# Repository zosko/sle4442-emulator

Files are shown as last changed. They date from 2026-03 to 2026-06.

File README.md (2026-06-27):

# SLE4442 Emulator
This is a smartcard emulator for ATMEGA8 microcontroller.

## Schematic
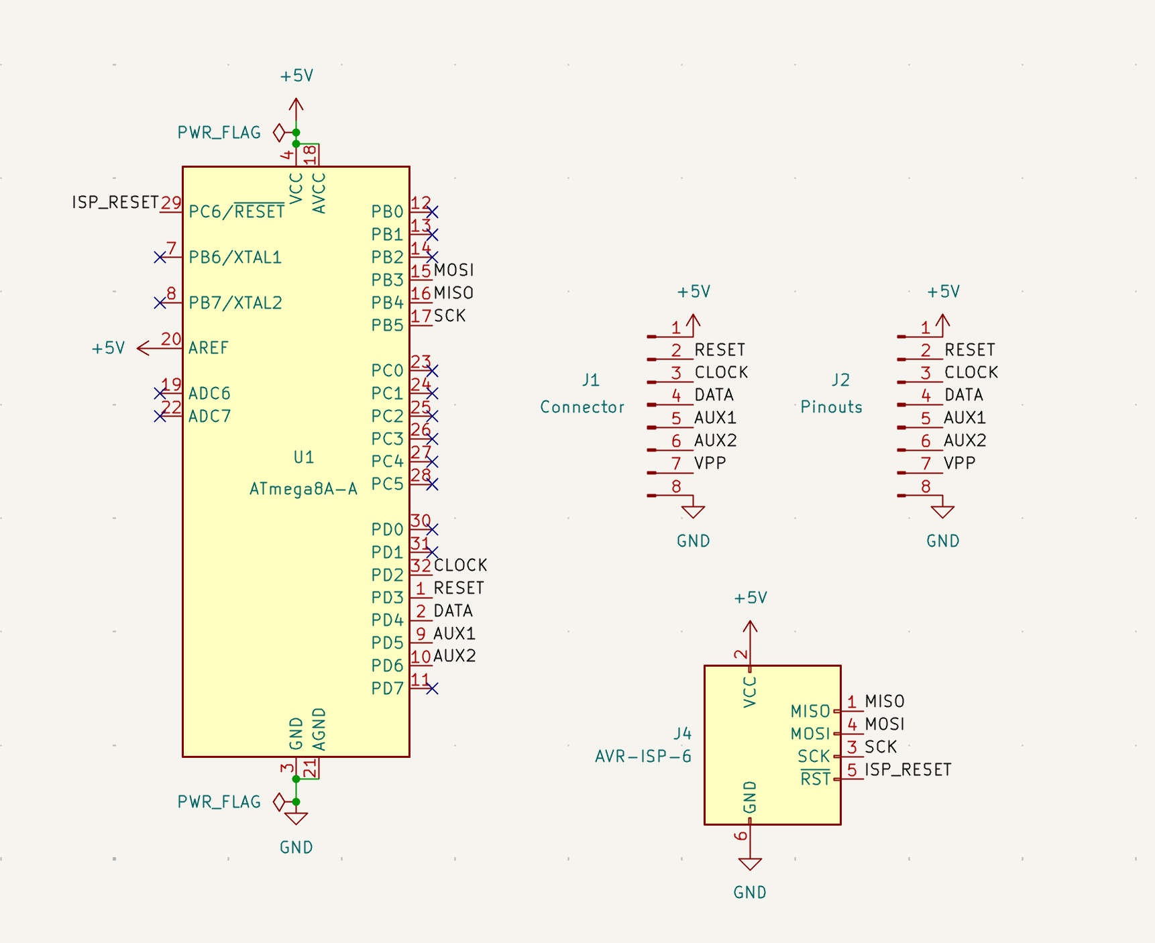
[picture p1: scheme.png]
Schematic


## Schematic
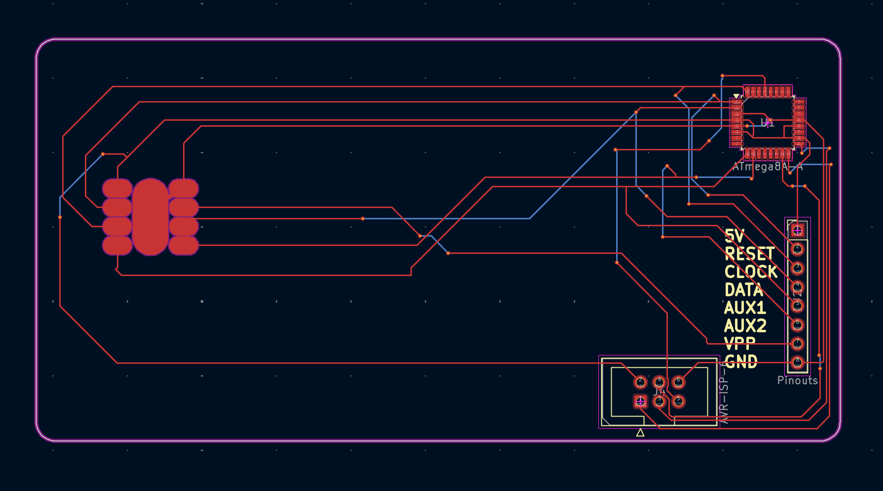
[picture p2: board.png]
Board


## Instructions
- Modify the "memory.h" file with the data of the card that you want to emulate
- If you compile the file with "#define BACKDOOR" uncommented, you will emulate a card that will be unlocked using any PSC code. Also, the PSC code sent by the reader will be updated immediately on the Security memory.  
- **WARNING**  
The maximum input clock frequency will be around 35KHz, not the 50KHz specified in the SLE4442 datasheet. I've tried my best to optimize the code but this is the main limitation of this project, you can try to use an external 16MHz clock for a better performance.

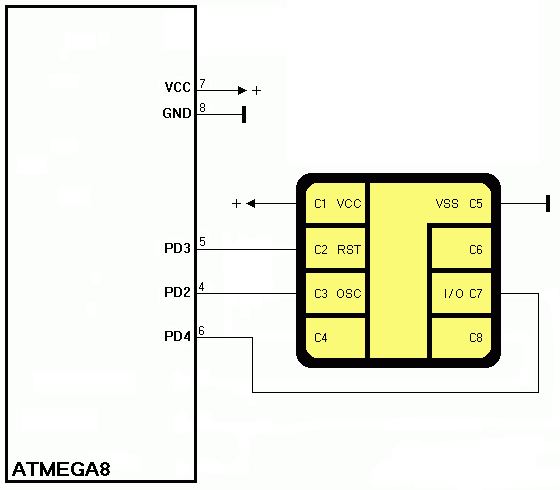
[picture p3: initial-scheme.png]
Old

Real scheme used from https://github.com/sonovice/sle4442.

# Programming instruction
```
brew tap osx-cross/avr
brew install avr-gcc avrdude
```

The following commands are for USBasp programmer. For other programmers, look at the avrdude documentation.  

## Writing fuses
Execute those commands only one time, no need to write fuses every time you burn the flash.
```
make fuses
```

## Burning
Go in `code` folder. Execute this command:

```
make flash
```

## Read EEPROM
Once the PSC is grabbed, you can read the microcontroller EEPROM using this command:
```
make read
```

Open **eeprom.hex** with a text editor, PSC is present here:


## Sponsorship

PCBWay_logo

**This project is proudly sponsored by [PCBWay](https://pcbway.com).**

PCBWay specializes in manufacturing high-quality printed circuit boards (PCBs), making them accessible and affordable for both hobbyists and professionals.

Their range of services includes:

- PCB prototyping
- Assembly services
- Instant order quotations
- Expert verification processes
- A user-friendly, hassle-free ordering system

I'm sincerely grateful to PCBWay for their generous support in making this project possible.

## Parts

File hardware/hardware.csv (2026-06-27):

Reference | Qty | Value | MPN | LCSC Part #
J1 | 1 | Connector
J2 | 1 | Pinouts
J4 | 1 | AVR-ISP-6
U1 | 1 | ATmega8A-A | ATMEGA8A-AU | C16190
Y1 | 1 | 16Mhz | CSTCE16M0V53-R0 | C32180

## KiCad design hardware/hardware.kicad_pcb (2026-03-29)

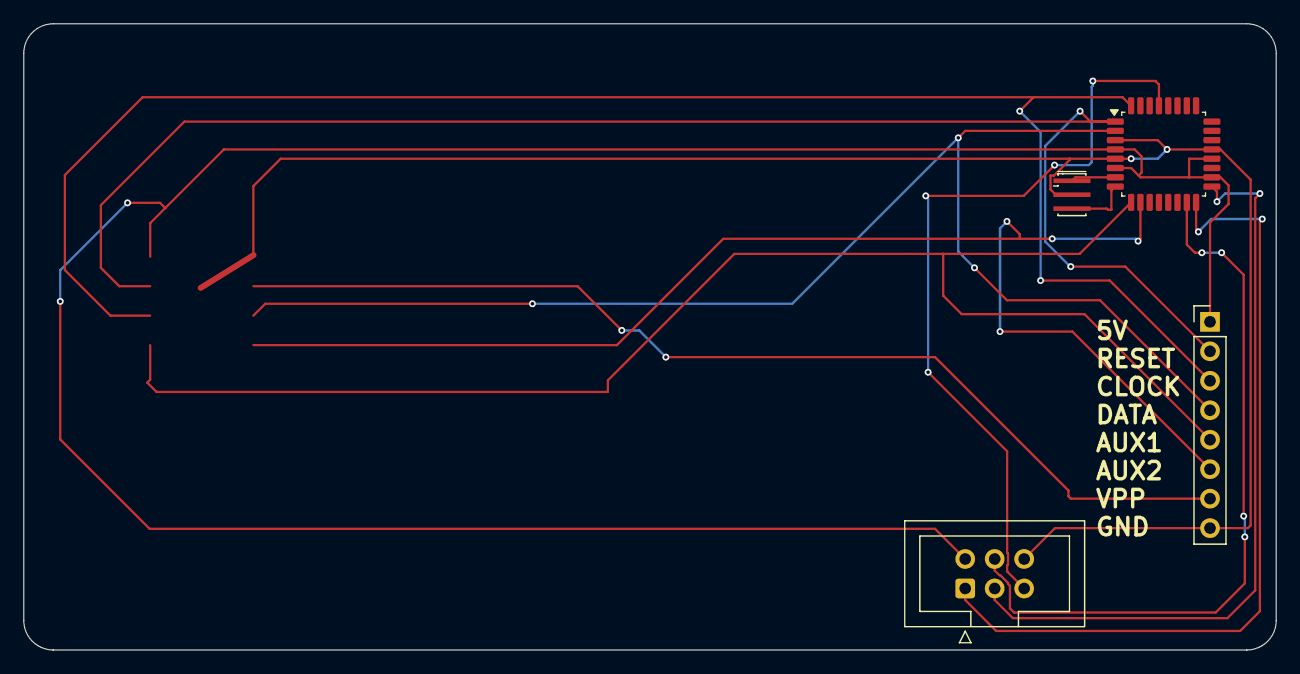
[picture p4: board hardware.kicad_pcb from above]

Board: 2 copper layers, 108.0 x 54.0 mm, 4 parts (0 on the bottom side), 13 nets.

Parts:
J2: Pinouts; PinHeader_1x08_P2.54mm_Vertical
J4: AVR-ISP-6; IDC-Header_2x03_P2.54mm_Vertical
U1: ATmega8A-A; TQFP-32_7x7mm_P0.8mm
Y1: 16Mhz; Resonator_SMD_Murata_CSTxExxV-3Pin_3.0x1.1mm_HandSoldering

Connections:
+5V: J2.1, J4.2 (VCC), U1.4 (VCC), U1.6 (VCC), U1.18 (AVCC), U1.20 (AREF)
/AUX1: J2.5, U1.9 (PD5)
/AUX2: J2.6, U1.10 (PD6)
/CLOCK: J2.3, U1.32 (PD2)
/DATA: J2.4, U1.2 (PD4)
/ISP_RESET: J4.5 (~RST), U1.29 (PC6/~RESET)
/MISO: J4.1 (MISO), U1.16 (PB4)
/MOSI: J4.4 (MOSI), U1.15 (PB3)
/RESET: J2.2, U1.1 (PD3)
/SCK: J4.3 (SCK), U1.17 (PB5)
GND: J2.8, J4.6 (GND), U1.3 (GND), U1.5 (GND), U1.21 (AGND), Y1.2
unnamed: U1.7 (PB6/XTAL1), Y1.1
unnamed: U1.8 (PB7/XTAL2), Y1.3

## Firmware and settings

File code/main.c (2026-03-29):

// cpu: ATMega8
// speed: 8 MHz

//#define DEBUG
#define BACKDOOR

#define F_CPU 8000000UL
#include "sle4442.h"
#include "memory.h"
#include <avr/io.h>
#include <util/delay.h>
#include <stdlib.h>
#include <stdio.h>
#include <stdlib.h>

volatile unsigned char is_start = 0;
volatile unsigned char is_stop = 0;
volatile unsigned char data_out = 0;
volatile unsigned char data_in = 0;
volatile unsigned char is_falling=0;
volatile unsigned char is_rising=0;
volatile unsigned char exec_reset=0;

volatile unsigned char count=0;
volatile unsigned char control=0;
volatile unsigned int  addr=0;
volatile unsigned char data=0;
volatile unsigned char cmd=0;
volatile unsigned char fail=0;
volatile unsigned char byteProt=0;
volatile unsigned char bitProt=0;
volatile unsigned char *memPtr;

void EEPROM_write(unsigned int uiAddress, unsigned char ucData)
{
    /* Wait for completion of previous write */
    while(EECR & (1<<EEWE));
    /* Set up address and data registers */
    EEAR = uiAddress;EEDR = ucData;
    /* Write logical one to EEMWE */
    EECR |= (1<<EEMWE);
    /* Start eeprom write by setting EEWE */
    EECR |= (1<<EEWE);
}

void store_psc()
{
    cli();
    EEPROM_write(0x00,memorySecurity[1]);
    EEPROM_write(0x01,memorySecurity[2]);
    EEPROM_write(0x02,memorySecurity[3]);
    sei();
}

static inline void  falling_clock()
{
    data_out = (memPtr[addr] >> pointerBit) & 0x01;
    
    if (control==0xFF)  //Fake "control" value for put at the output the ATR
    {
        if (addr==4 && pointerBit==1)
        {
            setInput();
            mode = MODE_WAIT_START;
            count = 0;
        }
    }
    else if (control==0x30)
    {
        if (addr==256 && pointerBit==1)
        {
            setInput();
            mode = MODE_WAIT_START;
            count = 0;
        }
    }
    else if (control==0x34)
    {
        if (addr==4 && pointerBit==1)
        {
            setInput();
            mode = MODE_WAIT_START;
            count = 0;
        }
    }
    else if (control==0x31)
    {
        if (addr==4 && pointerBit==1)
        {
            setInput();
            mode = MODE_WAIT_START;
            count = 0;
        }
    }
    else if (fail)
    {
        if (addr==0 && pointerBit==3)
        {
            fail = 0;
            setInput();
            mode = MODE_WAIT_START;
            count = 0;
        }
    }
    else if ((control==0x38 || control==0x3C) && fail==0)
    {
        if (addr==15 && pointerBit==5)  //15*8 + 5 = 125
        {
            setInput();
            mode = MODE_WAIT_START;
            count = 0;
        }
    }
    
    pointerBit++;
    if (pointerBit==8)
    {
        pointerBit = 0;
        addr++;
    }
}

static inline void  rising_clock()
{
    cmd = (cmd << 1) | data_in;
    if (count==7) //control ready
        control = lut[cmd];
    else if (count==15) //address ready
    {
        addr = lut[cmd];
        //Put as output all zero, if i found a read command i change the pointer value
        memPtr = memoryZero;
        if (control==0x30) //Read Main Memory
            memPtr = memoryMain;
        else if (control==0x34) //Read Protection Memory
        {
            addr = 0;
            memPtr = memoryProtected;
        }
        else if (control==0x31) //Read Security Memory
        {
            addr = 0;
            memoryOut[0] = memorySecurity[0];
            if (unlocked == 3)
                memPtr = memorySecurity;
            else
                memPtr = memoryOut;
        }
        byteProt = (addr >> 3) & 0x03;
        bitProt = addr & 0x07;
    }
    else if (count==16) //Use this extra counter value to execute some instructions
    {
        fail = 1;
        if (control==0x38 && unlocked==3) //Update main memory
        {
            if (addr>31)
                fail = 0;
            else
                fail = !((memoryProtected[byteProt] >> bitProt) & 0x01);
        }
        else if (control==0x3C && unlocked==3) //Write protection memory
        {
            if ((memoryProtected[byteProt] >> bitProt) & 0x01)
                fail = 0;
            addr = 0;
        }
        
    }
    else if (count==23) //data ready
    {
        mode = MODE_WAIT_STOP;
        pointerBit = 0;
        data = lut[cmd];
        
        if (control==0x38) //Update main memory
        {
            if (!fail)
                memoryMain[addr] = data;
            addr = 0;
        }
        else if (control==0x3C) //Write protection memory
        {
            if (!fail)
                memoryProtected[byteProt] &= ~(1 << bitProt);
            addr = 0;
        }
        else if (control==0x39) //Update security memory
        {
            if (unlocked == 3)
            {
                memorySecurity[addr] = data;
                memorySecurity[0x00] &= 0x07;
                fail = 0;
            }
            else if (addr == 0x00)
            {
                if (data <= memorySecurity[0x00])
                {
                    memorySecurity[0x00] = data;
                    fail = 0;
                }
                else
                fail = 1;
            }
            addr = 0;
        }
        else if (control==0x33) //Compare verification data
        {
            #ifdef BACKDOOR
                if (addr != 0)
                {
                    unlocked++;
                    memorySecurity[addr] = data;
                    if (unlocked >= 3)
                    {
                        unlocked = 3;
                        memorySecurity[0x00] = 0x07;
                    }       
                }
                addr = 0;
            #else
                if ((memorySecurity[addr] == data) & (memorySecurity[0x00] != 0x00))
                {
                    unlocked++;
                    if (unlocked >= 3)
                    {
                        unlocked = 3;
                        memorySecurity[0x00] = 0x07;
                    }
                }
                else
                    unlocked = 0;
                addr = 0;
            #endif
        }
        
        data_out = (unsigned char)(memPtr[addr]) & 0x01;
        pointerBit++;
    }
    
    count++;  
}

// Clock interrupt
ISR(INT0_vect)
{
    //SET_DBG
    data_in = (READ_IO) >> PIN_IO;  
    if (!(PIN & (1 << PIN_CLK)))
    {
        setIO(data_out);
        
        if (is_start && !data_in)
        {
            pointerBit = 0;
            setMode(MODE_CMD);
            is_start = 0;     
        }
        else if (is_stop && data_in)
        {
            setMode(MODE_OUT);
            setOutput();  
            is_stop=0;  
        }
 
        if (mode==MODE_OUT)
            falling_clock();
    }    
    else
    { 
        if (PIN & (1 << PIN_RST))
        {
            setOutput();
            setMode(MODE_OUT);
        }        
        else if (data_in && mode==MODE_WAIT_START)
            is_start = 1;         
        else if (!data_in && mode==MODE_WAIT_STOP)
            is_stop = 1;
        
        if (mode==MODE_CMD)
            rising_clock();       
    }   
    //RESET_DBG 
}

// Reset interrupt
ISR(INT1_vect)
{
    exec_reset = 1;
}

int main(void) {
    
    memPtr = memoryMain;
    
    unlocked = 0;
    
    // Activate interrupts
    MCUCR |= (1 << ISC00) | (1 << ISC11) | (1 << ISC10);
    
    GICR |= (1 << INT0) | (1 << INT1);
    sei();

    // Initialize port
    PORT = 0x00;
    DDR = 0x00;
    PIN = 0x00;
    DDR |= (1 << PIN_DBG);
    RESET_DBG
    setInput();
    setMode(MODE_WAIT_START);
    pointerBit =  0;
    count = 0;

    #ifdef DEBUG
    initializeDebug();
    #endif

    while(1)
    {
        //=============================================================
        // RESET ROUTINE
        //=============================================================
        if (exec_reset)
        {
            setInput();
            setMode(MODE_WAIT_START);
            pointerBit =  0;
            is_rising = 0;
            is_falling = 0;
            count = 0;
            addr = 0;
            control = 0xFF; //Fake "control" for ATR
            data_out = memoryMain[0] & 0x01;
            pointerBit++;
            exec_reset = 0;
        }
    }
}
